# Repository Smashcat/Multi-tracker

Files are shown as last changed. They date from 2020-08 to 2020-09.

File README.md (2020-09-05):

# Multi-tracker

### Tracking device dev board with Sigfox, Wifi and GPS functionality

This board is designed to allow testing and development of a tracking device using Sigfox, WiFi and GPS location tracking. It also breaks out all useful pins and indicators on both the WSS10R1AT Sigfox module, and the SIM28ML GPS module.

A P-channel mosfet supplies power to the GPS module, so that it can be enabled and disabled as needed to save power. The LEDs can also be enabled and disabled via a jumper, so that realistic power consumption tests can be performed if needed.

The ESP8266 has GPIO16 connected to reset, to allow the use of deep sleep, with timer interrupt wake.

The i2C pins from the ESP8266 are broken out onto the header, to allow connection of sensors, displays etc as needed. Additionally the ADC input from the ESP8266 has also been broken out - the input uses a voltage divider, so it can read voltages from 0 to around 3.3v.

Please note that this board is designed to run from 3.3V or lower, as it has no on-board voltage regulation. This is deliberate, as the board is designed for testing and development. If there is interest I will make another version more suited to outdoor use, with regulator, charging circuit etc to run from lithium Ion batteries or a USB charger.

Gerbers are included, ready to be submitted to JLCPCB or PCBWay (not tested with other services)

3D model render with CAD download can be found [here](https://a360.co/2Z3gr4b)

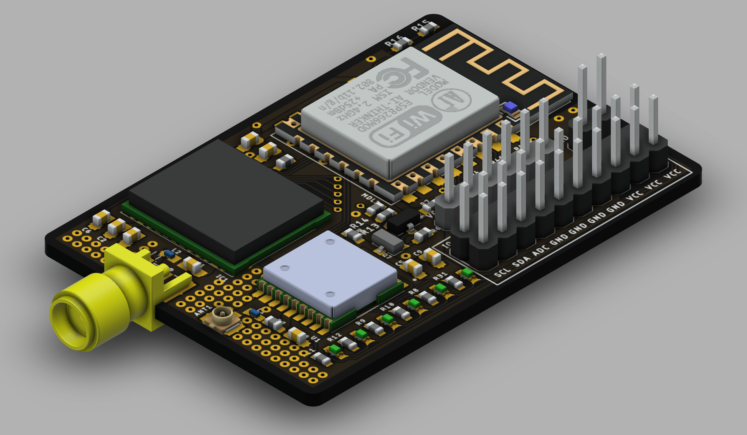
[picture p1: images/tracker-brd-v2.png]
Render


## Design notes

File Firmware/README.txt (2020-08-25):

Nothing to see here yet! This is a brand new design, and so firmware will be developed when I receive the first of these PCBs!

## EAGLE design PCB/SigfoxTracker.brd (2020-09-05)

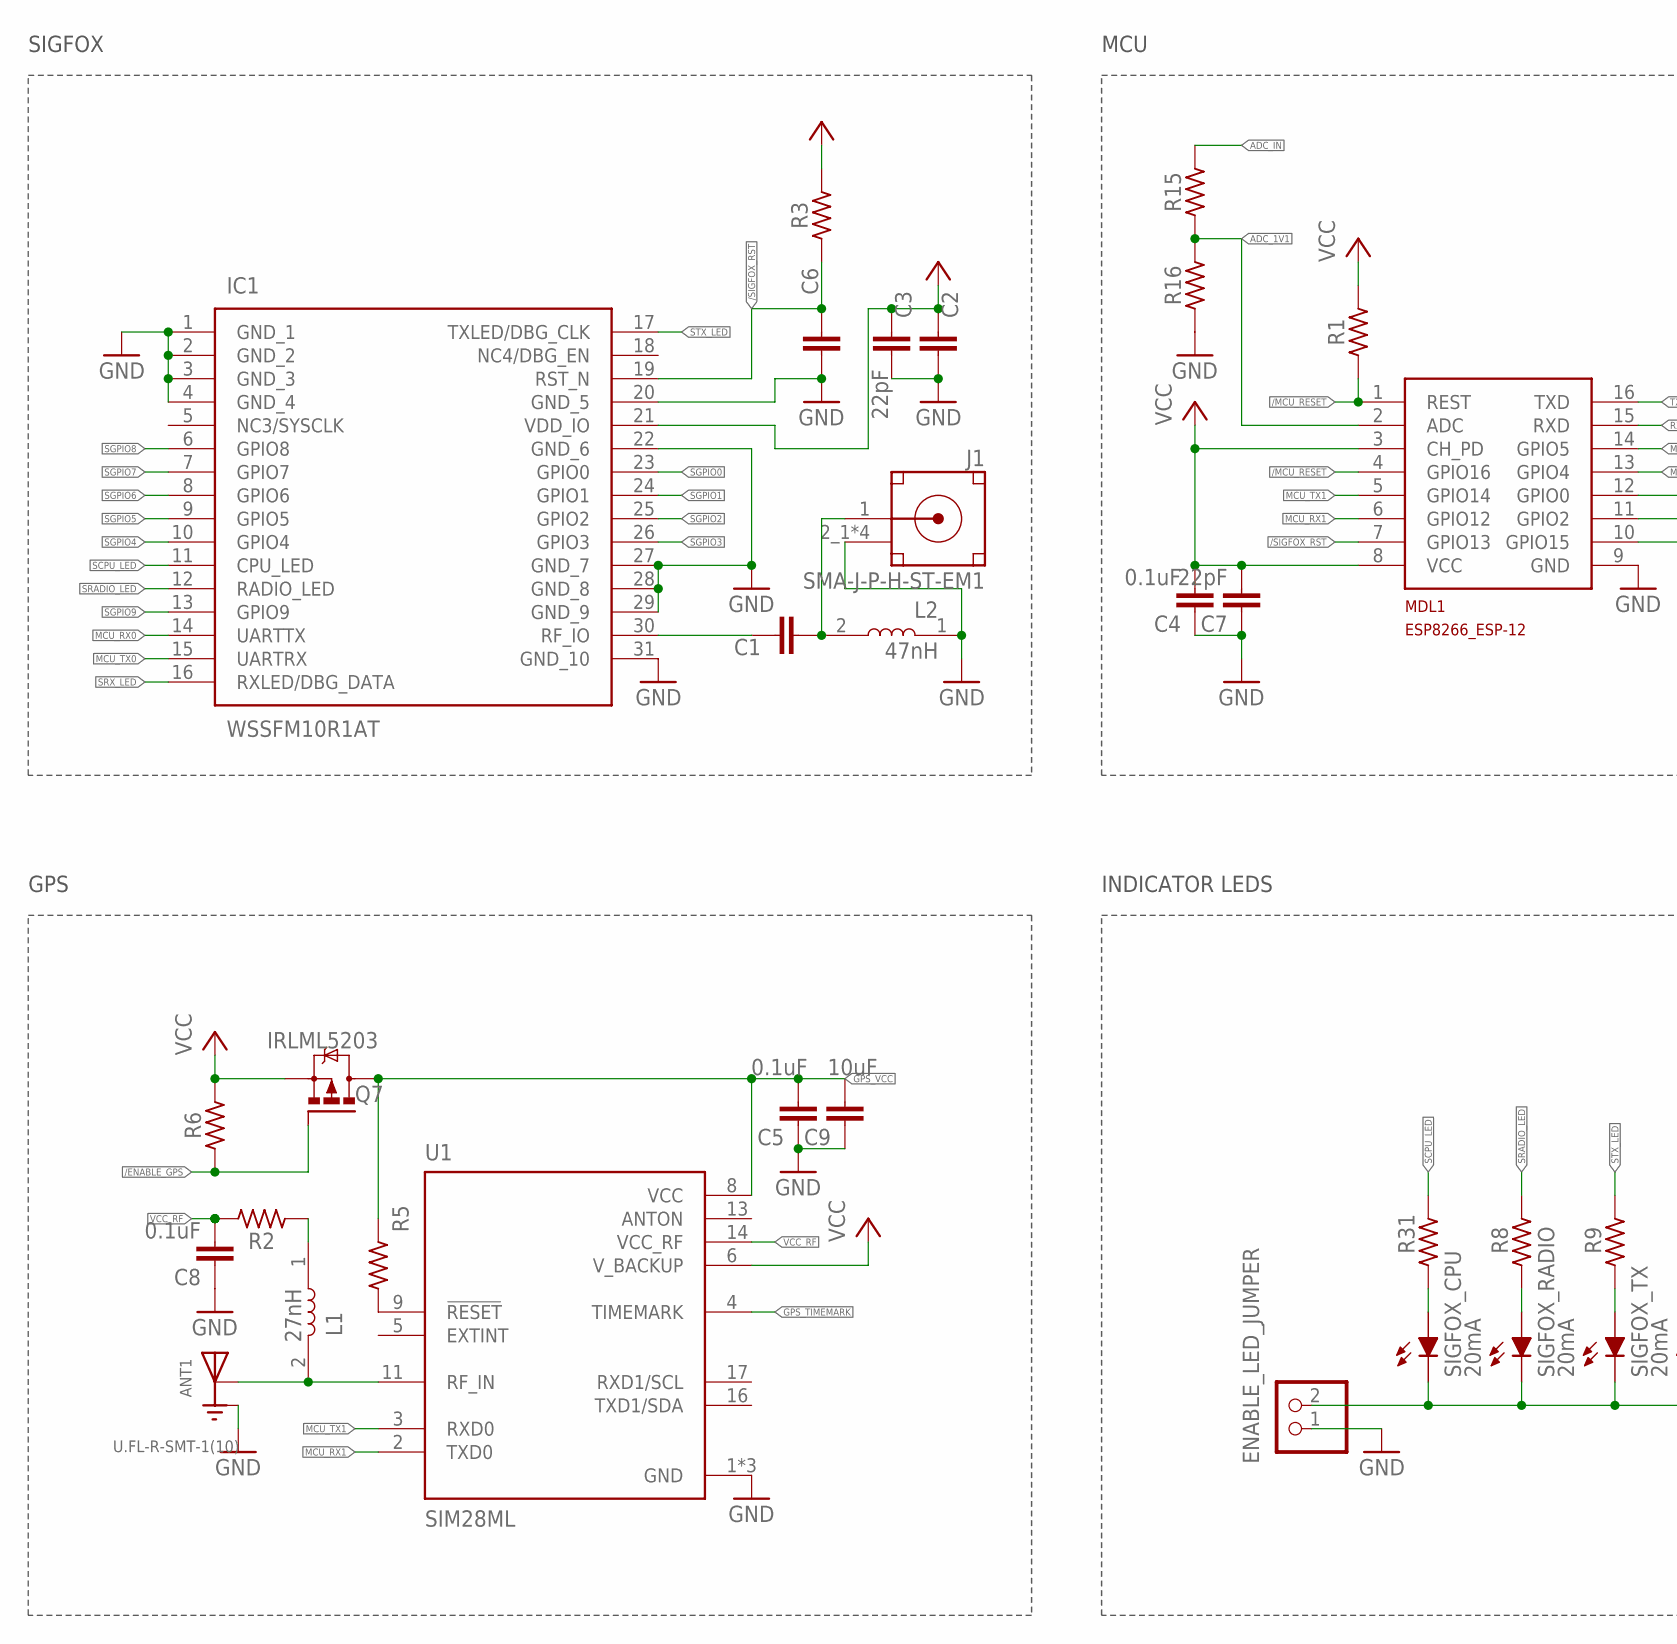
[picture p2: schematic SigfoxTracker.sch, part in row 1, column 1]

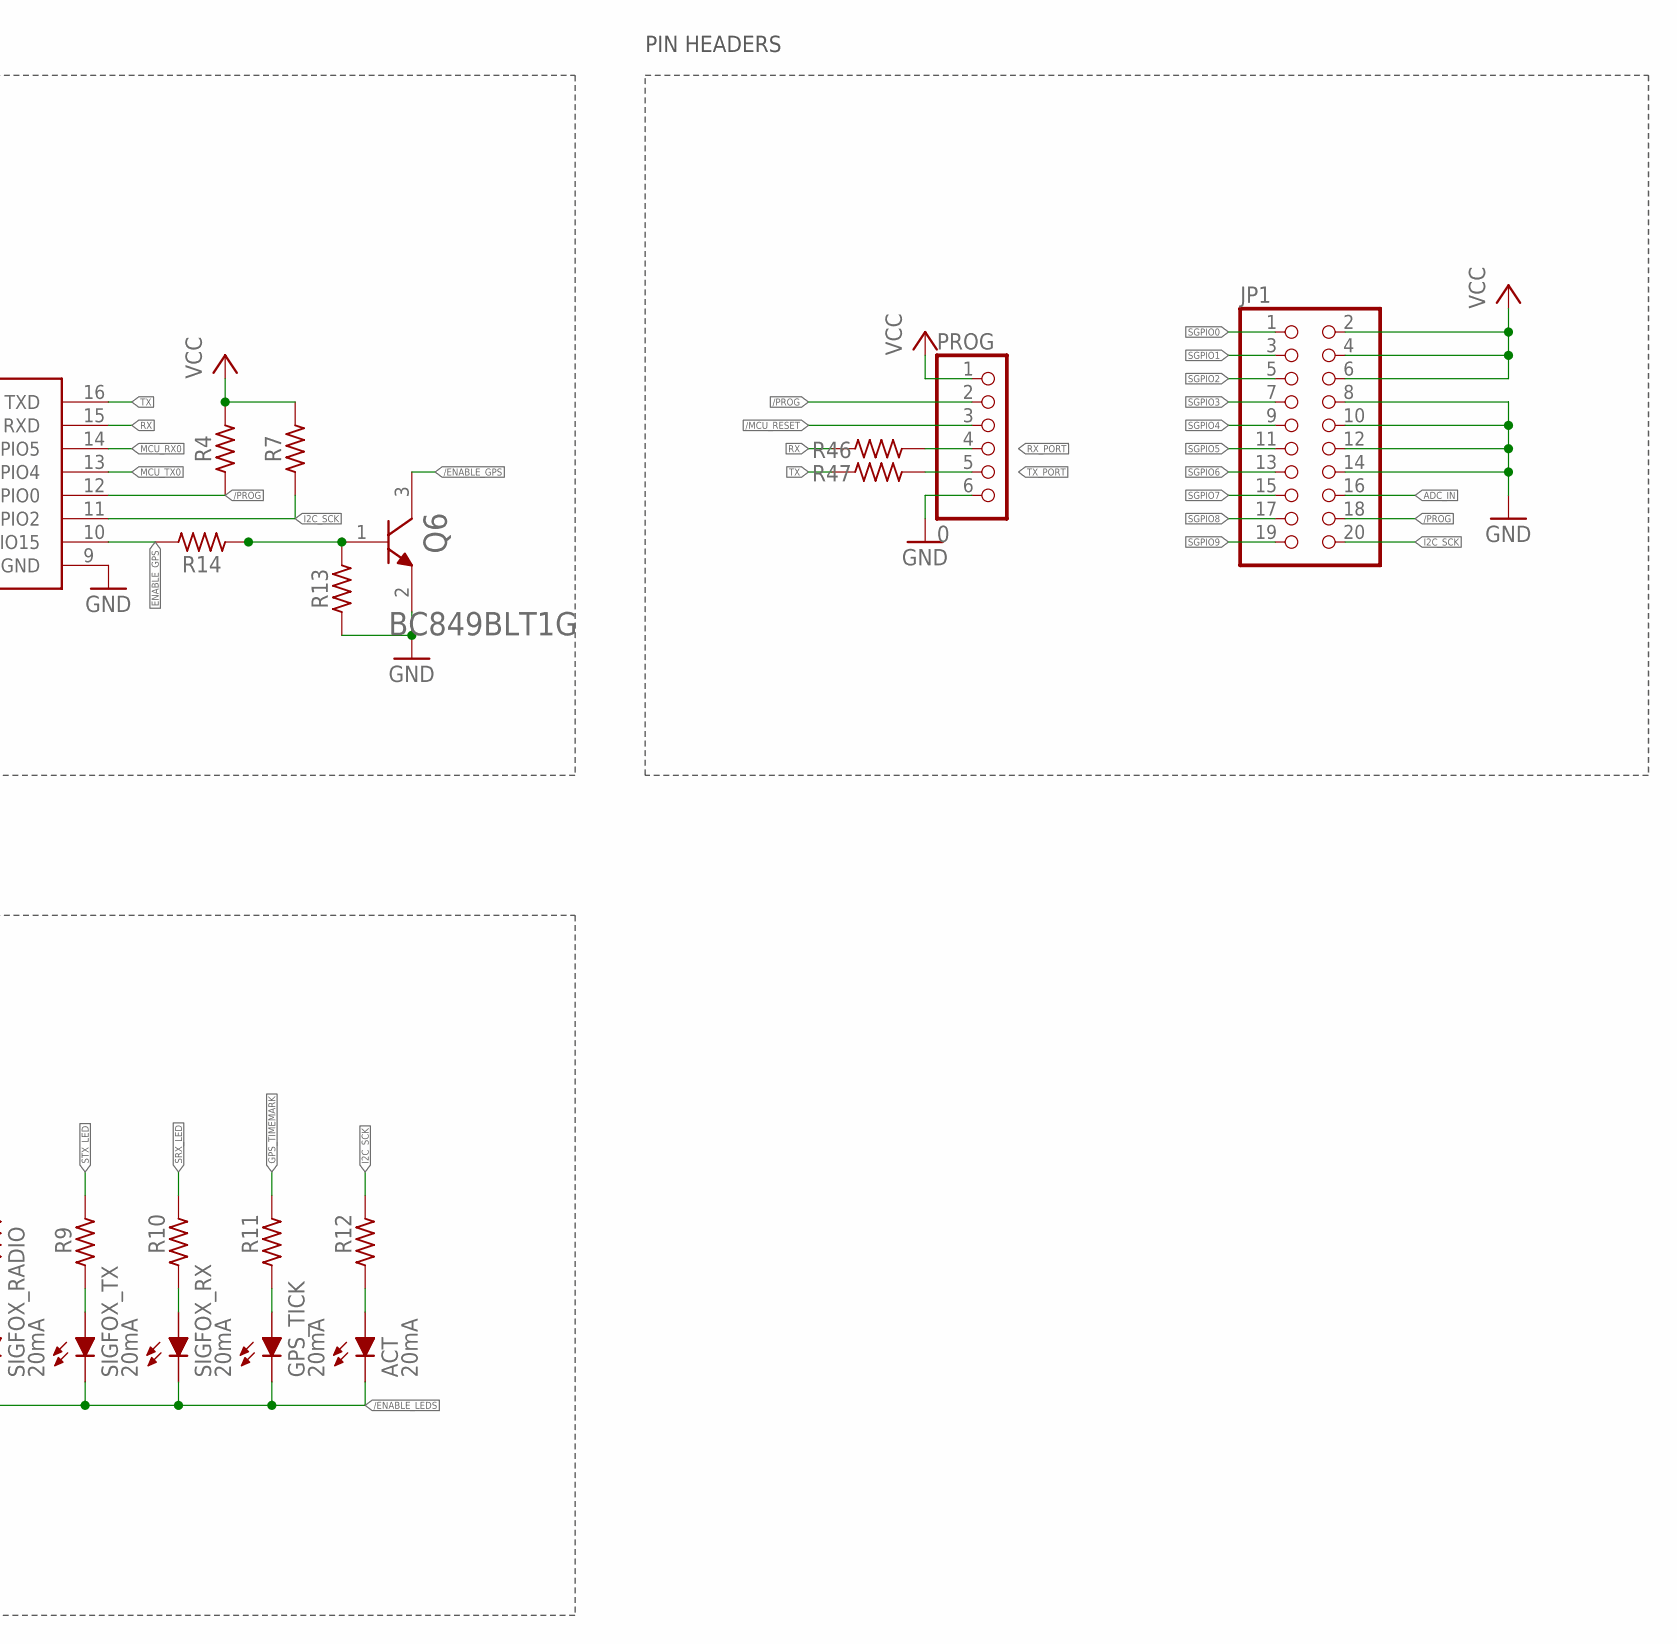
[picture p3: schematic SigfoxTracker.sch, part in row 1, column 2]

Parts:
ACT: 20mA; LED_CHIP-LED0603MP
ANT1: U.FL-R-SMT-1(10); HRS_U.FL-R-SMT-1(10)
C1: 100pF; C0603
C2, C4, C5, C6, C8: 0.1uF; C0603
C3, C7: 22pF; C0603
C9: 10uF; C0603
ENABLE_LED_JUMPER: PINHD-1X2; 1X02
GPS_TICK: 20mA; LED_CHIP-LED0603MP
IC1: WSSFM10R1AT
J1: SMA-J-P-H-ST-EM1
JP1: PINHD-2X10; 2X10
L1: 27nH; INDC1005X45
L2: 47nH; INDC1005X45
MDL1: MCU; ESP8266-ESP12
PROG: 0; 1X06
Q6: ON_SEMICONDUCTOR_BC849BLT1GON_SEMICONDUCTOR_BC849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; ON_SEMICONDUCTOR_BC849BLT1G_0
Q7: IRLML5203; MICRO3
R1, R5, R13: 100k; 52101-101-REV-A_RC-MASTER-SMD_R0603MP
R2: 10R; RC-MASTER-SMD_R0603MP
R3, R6: 100K; RC-MASTER-SMD_R0603MP
R4, R7: 4K7; 52101-101-REV-A_RC-MASTER-SMD_R0603MP
R8, R9, R10, R11, R12, R14, R31: 1K; 52101-101-REV-A_RC-MASTER-SMD_R0603MP
R15: 10K; 52101-101-REV-A_RC-MASTER-SMD_R0603MP
R16: 3V3; 52101-101-REV-A_RC-MASTER-SMD_R0603MP
R46, R47: 20R; RC-MASTER-SMD_R0603MP
SIGFOX_CPU: 20mA; LED_CHIP-LED0603MP
SIGFOX_RADIO: 20mA; LED_CHIP-LED0603MP
SIGFOX_RX: 20mA; LED_CHIP-LED0603MP
SIGFOX_TX: 20mA; LED_CHIP-LED0603MP
U1: SIM28ML; XCVR_SIM28ML

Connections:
/ENABLE_GPS: Q6.3 (C), Q7.1 (G), R6.1
/ENABLE_LEDS: ACT.C, ENABLE_LED_JUMPER.2, GPS_TICK.C, SIGFOX_CPU.C, SIGFOX_RADIO.C, SIGFOX_RX.C, SIGFOX_TX.C
/MCU_RESET: MDL1.1 (REST), MDL1.4 (GPIO16), PROG.3, R1.1
/PROG: JP1.18, MDL1.12 (GPIO0), PROG.2, R4.1
/SIGFOX_RST: C6.1, IC1.19 (RST_N), MDL1.7 (GPIO13), R3.1
ADC_1V1: MDL1.2 (ADC), R15.1, R16.2
ADC_IN: JP1.16, R15.2
ANTON: U1.13 (ANTON)
ENABLE_GPS: MDL1.10 (GPIO15), R14.2
GND: ANT1.1 (GND), ANT1.3 (GND), C2.1, C3.1, C4.1, C5.1, C6.2, C7.1, C8.1, C9.1, ENABLE_LED_JUMPER.1, IC1.1 (GND_1), IC1.2 (GND_2), IC1.3 (GND_3), IC1.4 (GND_4), IC1.20 (GND_5), IC1.22 (GND_6), IC1.27 (GND_7), IC1.28 (GND_8), IC1.29 (GND_9), IC1.31 (GND_10), J1.2_1 (GND), J1.2_2 (GND), J1.3_1 (GND), J1.3_2 (GND), JP1.8, JP1.10, JP1.12, JP1.14, L2.1, MDL1.9 (GND), PROG.6, Q6.2 (E), R13.1, R16.1, U1.1 (GND), U1.10 (GND), U1.12 (GND)
GPS_TIMEMARK: R11.1, U1.4 (TIMEMARK)
GPS_VCC: C5.2, C9.2, Q7.3 (D), R5.2, U1.8 (VCC)
I2C_SCK: JP1.20, MDL1.11 (GPIO2), R7.1, R12.1
MCU_RX0: IC1.14 (UARTTX), MDL1.14 (GPIO5)
MCU_RX1: MDL1.6 (GPIO12), U1.2 (TXD0)
MCU_TX0: IC1.15 (UARTRX), MDL1.13 (GPIO4)
MCU_TX1: MDL1.5 (GPIO14), U1.3 (RXD0)
unnamed: R5.1, U1.9 (!RESET)
unnamed: C1.2, J1.1 (SIGNAL), L2.2
unnamed: L1.1, R2.1
unnamed: R8.2, SIGFOX_RADIO.A
unnamed: R9.2, SIGFOX_TX.A
unnamed: R10.2, SIGFOX_RX.A
unnamed: GPS_TICK.A, R11.2
unnamed: ACT.A, R12.2
unnamed: R31.2, SIGFOX_CPU.A
unnamed: Q6.1 (B), R13.2, R14.1
RF_IN: ANT1.2 (SIG), L1.2, U1.11 (RF_IN)
RX: MDL1.15 (RXD), R46.1
RX_PORT: PROG.4, R46.2
SCPU_LED: IC1.11 (CPU_LED), R31.1
SGPIO0: IC1.23 (GPIO0), JP1.1
SGPIO1: IC1.24 (GPIO1), JP1.3
SGPIO2: IC1.25 (GPIO2), JP1.5
SGPIO3: IC1.26 (GPIO3), JP1.7
SGPIO4: IC1.10 (GPIO4), JP1.9
SGPIO5: IC1.9 (GPIO5), JP1.11
SGPIO6: IC1.8 (GPIO6), JP1.13
SGPIO7: IC1.7 (GPIO7), JP1.15
SGPIO8: IC1.6 (GPIO8), JP1.17
SGPIO9: IC1.13 (GPIO9), JP1.19
SIGFOX_RF_IO: C1.1, IC1.30 (RF_IO)
SRADIO_LED: IC1.12 (RADIO_LED), R8.1
SRX_LED: IC1.16 (RXLED/DBG_DATA), R10.1
STX_LED: IC1.17 (TXLED/DBG_CLK), R9.1
TX: MDL1.16 (TXD), R47.1
TX_PORT: PROG.5, R47.2
VCC: C2.2, C3.2, C4.2, C7.2, IC1.21 (VDD_IO), JP1.2, JP1.4, JP1.6, MDL1.3 (CH_PD), MDL1.8 (VCC), PROG.1, Q7.2 (S), R1.2, R3.2, R4.2, R6.2, R7.2, U1.6 (V_BACKUP)
VCC_RF: C8.2, R2.2, U1.14 (VCC_RF)

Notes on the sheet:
SIGFOX
GPS
INDICATOR LEDS
MCU
PIN HEADERS

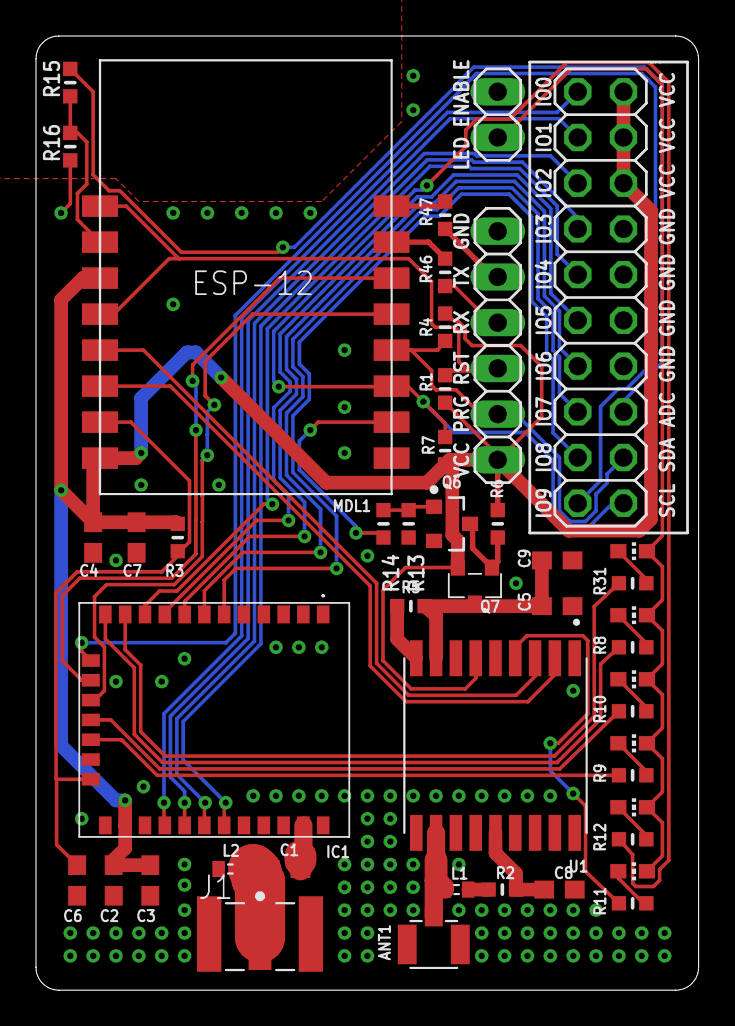
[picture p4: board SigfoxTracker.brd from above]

Board: 2 copper layers, 36.8 x 53.0 mm, 46 parts (0 on the bottom side), 48 nets.

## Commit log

2020-08-25 Adding files
    [SigfoxTracker.brd, SigfoxTracker.sch]
2020-08-25 Added some labels for LEDs to back of board
    [SigfoxTracker.brd, SigfoxTracker.sch]
2020-08-29 More stitching, cleaned up schematic
    [SigfoxTracker.brd, SigfoxTracker.sch]
2020-08-29 New Gerbers and updated README
2020-09-05 New revision, broken out i2C, ADC input, changed silkscreen
    [SigfoxTracker.brd, SigfoxTracker.sch]
2020-09-05 Updated README with details to reflect the updated board design
